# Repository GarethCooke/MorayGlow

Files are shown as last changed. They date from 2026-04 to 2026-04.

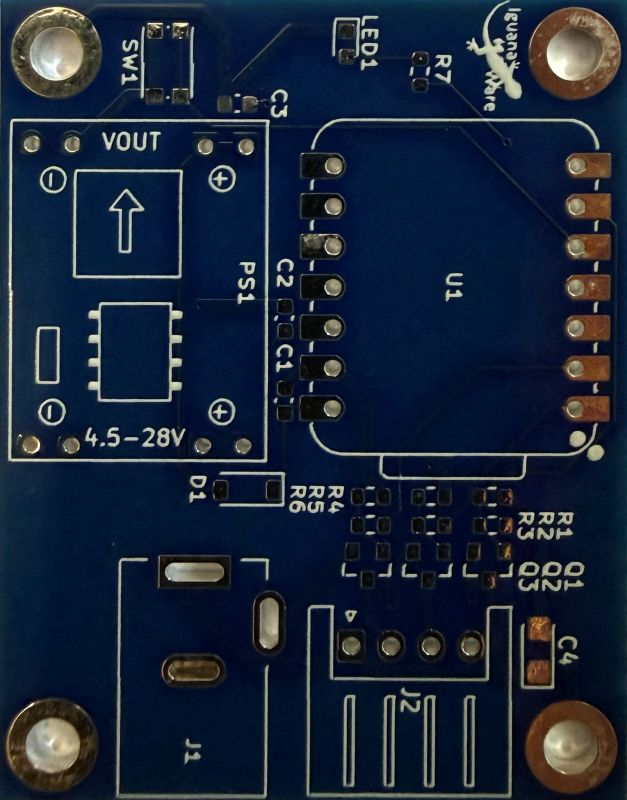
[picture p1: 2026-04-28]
docs/pcb-front.jpg

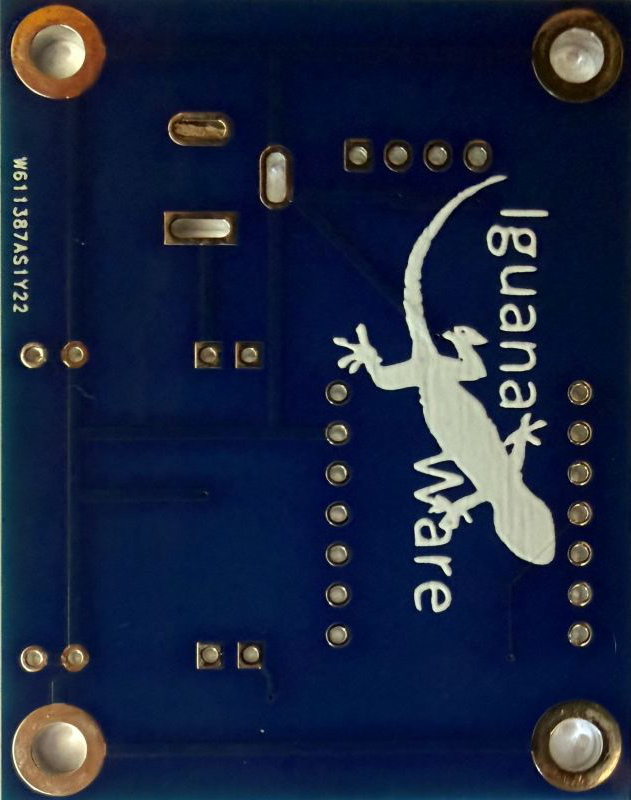
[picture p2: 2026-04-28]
docs/pcb-back.jpg

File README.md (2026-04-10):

# MorayGlow

IoT LED strip controller — ESP32 firmware + web UI with Home Assistant integration.

## Project Summary

MorayGlow controls an RGB LED strip via an **ESP32**. The device hosts a web UI and exposes a REST + WebSocket API. A browser-based client lets you toggle the strip on/off and pick a colour. The device also integrates with **Home Assistant** via MQTT auto-discovery, so it appears automatically as a light entity.

## Project Structure

```text
MorayGlow/
├── MorayServer/               # ESP32 firmware (C++, PlatformIO)
│   ├── platformio.ini
│   ├── src/main.cpp            # WiFi, LittleFS, REST API, WebSocket
│   ├── include/
│   │   ├── config.h            # WiFi credentials, MQTT config — edit before flashing
│   │   ├── state.h             # Pure logic: stateToJson, rgbToHex, parseMqttCommand
│   │   └── mqtt.h              # MQTT client + Home Assistant discovery
│   └── test/
│       └── test_state.cpp      # Unity tests (run on host, not device)
└── MorayClient/               # Web UI (plain HTML/CSS/JS — no framework)
    ├── index.html
    ├── css/style.css
    ├── js/
    │   ├── moray.js           # UMD utility module (buildWsUrl, isValidHexColor)
    │   └── app.js              # Main UI logic
    ├── test/
    │   └── moray.test.js      # Jest tests for moray.js
    └── test-server/            # Node.js mock server for UI development
        ├── server.js
        ├── logic.js            # Pure functions (testable without starting server)
        ├── db.json             # Persisted state between restarts
        └── test/
            └── server.test.js  # Jest tests for logic.js
```

## API

| Method | Endpoint | Body | Description |
| --- | --- | --- | --- |
| GET | `/api/state` | — | Returns `{"on": bool, "color": "#rrggbb"}` |
| POST | `/api/power` | `{"on": bool}` | Turn strip on or off |
| POST | `/api/color` | `{"color": "#rrggbb"}`  | Set strip colour |
| WS | `/ws` | — | Server pushes state on every change |

## Design Decisions

| Decision | Choice | Reason |
| --- | --- | --- |
| MCU | ESP32 Dev Board | Dual-core, Wi-Fi + Bluetooth built in |
| Build system | PlatformIO | Dependency management, board config, native test env |
| Web server | `esphome/ESPAsyncWebServer-esphome` | Supports ESP32; async |
| Filesystem | LittleFS | Serves client files from device flash |
| JSON | ArduinoJson v7 (`JsonDocument`) | No capacity arg needed; widely supported |
| MQTT | `knolleary/PubSubClient` + `setBufferSize(512)` | Lightweight, well-maintained |
| HA integration | MQTT auto-discovery | Device appears automatically in Home Assistant |
| Client | Plain HTML/CSS/JS (no framework) | Keeps LittleFS footprint small |
| Client module  | UMD pattern (`moray.js`) | Works as browser global and Node.js/Jest module |
| Testability | Pure functions in `state.h` / `logic.js` | Compiled and tested on host without hardware |
| C++ tests | Unity (via PlatformIO native env) | Bundled with PlatformIO; runs on host |
| JS tests | Jest | Standard, zero-config for CommonJS modules |

## Before Flashing

Edit `MorayServer/include/config.h` and set your WiFi SSID/password and MQTT broker IP before building and flashing.

## Running Tests

### MorayServer — C++ firmware (Unity via PlatformIO)

Requires `gcc`/`g++` on your PATH (install MinGW-w64 if not present).

```powershell
cd MorayServer
pio test -e native
```

### MorayClient — browser JS logic (Jest)

```powershell
cd MorayClient
npm install   # first time only
npm test
```

### Test server — Node.js logic (Jest)

```powershell
cd MorayClient\test-server
npm install   # first time only
npm test
```

---

## Starting the Test Server

The test server lets you develop and test the web UI without the physical device.

```powershell
cd MorayClient\test-server
npm install   # first time only
npm start
```

Then open [http://localhost:3000](http://localhost:3000) in a browser.

State is persisted to `MorayClient\test-server\db.json` between restarts.

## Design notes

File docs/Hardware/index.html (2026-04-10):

# MorayGlow — XIAO ESP32-S3 RGB LED Strip Controller

12 V 5050 RGB LED strip controller · Available as SMD or through-hole build

Seeed XIAO ESP32-S3 LEDC PWM 1 kHz 8-bit 12 V input · MP1584 buck SMD: IRLML6344TR SOT-23 TH: IRL540N TO-220 PlatformIO · ESP-IDF

## Schematic

Note: This schematic shows the circuit topology, which is identical for both SMD and through-hole builds. Only the package outlines differ — see the BOM and Assembly Notes sections below for component substitutions.

## Power Domains

+12V

J1 barrel jack → C3 (100nF) → MP1584 buck input · J2 pin-1 (strip common anode)
Main supply rail. Strip current limited by LED density; buck draws <200 mA additional.

+5V

MP1584 OUT → D1 (1N5819 Schottky, ~0.3V drop) → XIAO VBUS · C1 (100nF) · C2 (10µF)
Protected against USB/12V back-feed. XIAO draws <500 mA typical.

+3.3V

XIAO internal LDO → GPIO logic
LEDC outputs are 3.3 V — sufficient to drive both IRLML6344TR (Vgs(th)≈1.0V) and IRL540N (Vgs(th)≤2.0V).

GND

Common ground — J1 · MP1584 · XIAO GND pins · Q1–Q3 SOURCE · all pull-downs · LED1 · SW1 · C1–C3

## Pin Mapping

GPIO | XIAO Pin | Mode | LEDC | Function | Connected to
GPIO1 | D0 | PWM out | CH0 · 1kHz · 8-bit | Red channel | R1 (100Ω) → Q1 GATE
GPIO2 | D1 | PWM out | CH1 · 1kHz · 8-bit | Green channel | R2 (100Ω) → Q2 GATE
GPIO3 | D2 | PWM out | CH2 · 1kHz · 8-bit | Blue channel | R3 (100Ω) → Q3 GATE
GPIO4 | D3 | Digital out | — | Status LED | R7 (330Ω) → LED1 anode
GPIO5 | D4 | INPUT_PULLUP | — | Reset button | SW1 (active-LOW, hold 5s)

### Board Overview

XIAO ESP32-S3 front indication diagram

Seeed Studio XIAO ESP32-S3 — front view

### Full Pinout

XIAO ESP32-S3 pinout diagram

Source: Seeed Studio Wiki (https://wiki.seeedstudio.com/xiao_esp32s3_getting_started/)

## MOSFET Switch Topology

#### Circuit — identical for Q1 / Q2 / Q3

  GPIO ──[100Ω]──┬── GATE
                 │
               [10kΩ]
                 │          G
                GND         │
                         [MOSFET]
                            │ D ──── J2 (LED strip colour –)
                            │ S ──── GND

### Design rationale

Gate resistor (100Ω) | Limits inrush, damps ringing on fast PWM edges
Pull-down (10kΩ) | Holds gate LOW during boot / GPIO hi-Z — prevents strip flickering at reset
Common-anode strip | +12V to strip anode; MOSFETs sink each colour cathode
Logic compatibility | Both SMD and TH MOSFETs fully enhance at 3.3V — no level shifter needed

#### SMD — IRLML6344TR

Package | SOT-23
Vgs(th) | 0.5–1.5V (typ 1.0V)
Rds(on) | 22 mΩ @ Vgs = 4.5V
Id(max) | 5 A
Pinout | G · S · D (SOT-23 1·2·3)
Best for | PCB / compact design

#### Through-Hole — IRL540N

Package | TO-220
Vgs(th) | 1.0–2.0V (fully on at 3.3V)
Rds(on) | 77 mΩ @ Vgs = 5V · ≈120 mΩ @ 3.3V
Id(max) | 36 A
Pinout | G · D · S (flat face, left→right)
Best for | Breadboard / perfboard / stripboard

## Bill of Materials

SMD Build Through-Hole Build

Ref | Qty | Value | Description | Package | Part number
U1 | 1 | XIAO ESP32-S3 | Seeed XIAO ESP32-S3 Plus, castellated SMD | Module (castellated) | Seeed 113991116
Q1 | 1 | IRLML6344TR | N-Ch MOSFET, Vgs(th)≈1.0V, Id=5A — Red channel | SOT-23 | IRLML6344TRPBFCT-ND
Q2 | 1 | IRLML6344TR | N-Ch MOSFET, Vgs(th)≈1.0V, Id=5A — Green channel | SOT-23 | IRLML6344TRPBFCT-ND
Q3 | 1 | IRLML6344TR | N-Ch MOSFET, Vgs(th)≈1.0V, Id=5A — Blue channel | SOT-23 | IRLML6344TRPBFCT-ND
D1 | 1 | 1N5819HW-7-F | Schottky 40V 1A, USB/12V back-feed protection | SOD-123 | 1N5819HW-FDICT-ND
R1 R2 R3 | 3 | 100Ω | Gate resistors, 1/10W | 0603 | LCSC C22775
R4 R5 R6 | 3 | 10kΩ | Gate pull-downs, 1/10W | 0603 | LCSC C25804
R7 | 1 | 330Ω | Status LED current limiter, 1/10W | 0603 | LCSC C23138
C1 C3 | 2 | 100nF | Decoupling ceramic, 16–25V | 0603 | LCSC C14663
C2 | 1 | 10µF | Bulk cap, X5R 10V | 0805 | LCSC C15850
LED1 | 1 | LED Blue | Status indicator | 0805 | LCSC C72038
SW1 | 1 | SW_Push 6mm | Tactile pushbutton, SMD 4-pin | 6mm SMD | LCSC C318884
PS1 | 1 | MP1584 5V | Buck module 7–28V in / 5V 3A out | 2×2 header | Generic module
J1 | 1 | Barrel Jack | 12V DC input, 5.5/2.1mm SMD horizontal | SMD horizontal | LCSC C381116
J2 | 1 | Screw Term 4P | RGB strip connector, 3.5mm pitch SMD | 3.5mm SMD | LCSC C395916

Ref | Qty | Value | Description | Package | Part number | Notes
U1 | 1 | XIAO ESP32-S3 | Same XIAO module — mount in 2×7 female machine-pin sockets | 2×7 socket 2.54mm | Seeed 113991116 + sockets | XIAO has no TH pins — use castellated pad or pre-headered version
Q1 | 1 | IRL540N | N-Ch Logic Level MOSFET, Vgs(th)≤2.0V, Id=36A — Red | TO-220 | Digikey IRL540NPBF-ND | Pin order flat face L→R: G · D · S
Q2 | 1 | IRL540N | N-Ch Logic Level MOSFET, Vgs(th)≤2.0V, Id=36A — Green | TO-220 | Digikey IRL540NPBF-ND | No heatsink needed ≤3A/ch
Q3 | 1 | IRL540N | N-Ch Logic Level MOSFET, Vgs(th)≤2.0V, Id=36A — Blue | TO-220 | Digikey IRL540NPBF-ND | Rds(on) ≈ 100–150mΩ at 3.3V gate
D1 | 1 | 1N5819 | Schottky 40V 1A, USB/12V back-feed protection | DO-41 axial | LCSC C727110 | Cathode band (ring) toward XIAO VBUS
R1 R2 R3 | 3 | 100Ω | Gate resistors, 1/4W axial | DIN0207 10mm | LCSC C57430 | Carbon or metal film
R4 R5 R6 | 3 | 10kΩ | Gate pull-downs, 1/4W axial | DIN0207 10mm | LCSC C57690 | Carbon or metal film
R7 | 1 | 330Ω | Status LED current limiter, 1/4W axial | DIN0207 10mm | LCSC C57502 | Carbon or metal film
C1 C3 | 2 | 100nF | Decoupling ceramic disc, 50V — non-polarised | Disc 5mm pitch | LCSC C49678 | Orientation does not matter
C2 | 1 | 10µF 25V | Bulk cap, aluminium electrolytic radial | Radial 5mm pitch | LCSC C36369 | Long lead = positive (VBUS)
LED1 | 1 | LED Blue 5mm | Status indicator, 5mm through-hole | 5mm THT | LCSC C2296 | Long lead = anode; flat on lens = cathode
SW1 | 1 | SW_Push 6mm | Tactile pushbutton, 6×6mm through-hole | 6mm THT 4-pin | LCSC C318885 | Any orientation (leg pairs shorted internally)
PS1 | 1 | MP1584 5V | Same buck module — solder 2×2 headers, plug into board | 2×2 header | Generic module | Solder header pins to module first
J1 | 1 | Barrel Jack | 12V DC input, 5.5/2.1mm through-hole horizontal | THT horizontal | LCSC C136706 | Centre pin = +12V; sleeve = GND
J2 | 1 | Screw Term 4P | RGB strip connector, 3.5mm pitch through-hole | 3.5mm THT | LCSC C474870 | 5.08mm pitch also works: LCSC C8465

## Assembly Notes

● SMD-specific

1

IRLML6344TR SOT-23 pinout: looking at the component face with the marking text readable — pin 1 (Gate) is bottom-left, pin 2 (Source) is bottom-right, pin 3 (Drain) is at top. Use a fine-tip iron at 320°C.

2

1N5819HW SOD-123 polarity: the line on the body marks the cathode. On the PCB, the cathode side connects toward XIAO VBUS.

3

C2 0805 X5R: non-polarised ceramic — orientation does not matter. Solder last if hand-soldering to avoid disturbing adjacent small components.

● Through-hole-specific

1

IRL540N TO-220 pinout (flat face toward you, left→right): Gate · Drain · Source. Verify before soldering — incorrect orientation will short 12V to GND.

2

C2 electrolytic polarity: long lead = positive (+VBUS). Reversed polarity will destroy the cap. Mark the board clearly.

3

D1 (1N5819 DO-41) polarity: silver band = cathode. Cathode faces toward XIAO VBUS pin; anode faces MP1584 +5V output.

4

LED1 5mm polarity: long lead = anode. Current ≈ 4mA through R7 (330Ω from 3.3V) — sufficient for clear indicator visibility.

5

XIAO ESP32-S3: the module has no through-hole legs. Use 2×7 female machine-pin sockets soldered to the board so the module presses in. This also allows the module to be swapped without desoldering.

● Both builds

!

Test with low-voltage first: before connecting 12V, power the XIAO via USB and verify GPIO PWM signals at the gate resistor inputs with a multimeter. GATE voltage should cycle with PWM duty.

!

Power-up sequence: the 10kΩ gate pull-downs ensure all channels start OFF. The MP1584 module may take ~5ms to reach 5V; D1 prevents XIAO back-powering via USB when 12V is also connected.

## Firmware

### Build & Flash (PlatformIO)

# Build for XIAO ESP32-S3
pio run -e xiao_esp32s3

# Flash firmware
pio run -e xiao_esp32s3 -t upload

# Open serial monitor (115200 baud)
pio device monitor

⚠ XIAO GPIO restrictions
GPIO 19/20 = USB D+/D– — do not use for I/O.
GPIO 43/44 = TX/RX — keep free for Serial.

### Colour Cycle (3 s per step, auto-advance)

Red

Green

Blue

Yellow

Cyan

Magenta

White

Amber

### Reset Button Behaviour

Press < 5 s | No action
Holding… | Status LED blinks increasingly fast
Hold ≥ 5 s | 5× flash, then ESP.restart()
Debounce | 50 ms

MorayGlow — XIAO ESP32-S3 RGB LED Strip Controller · docs/Hardware/index.html

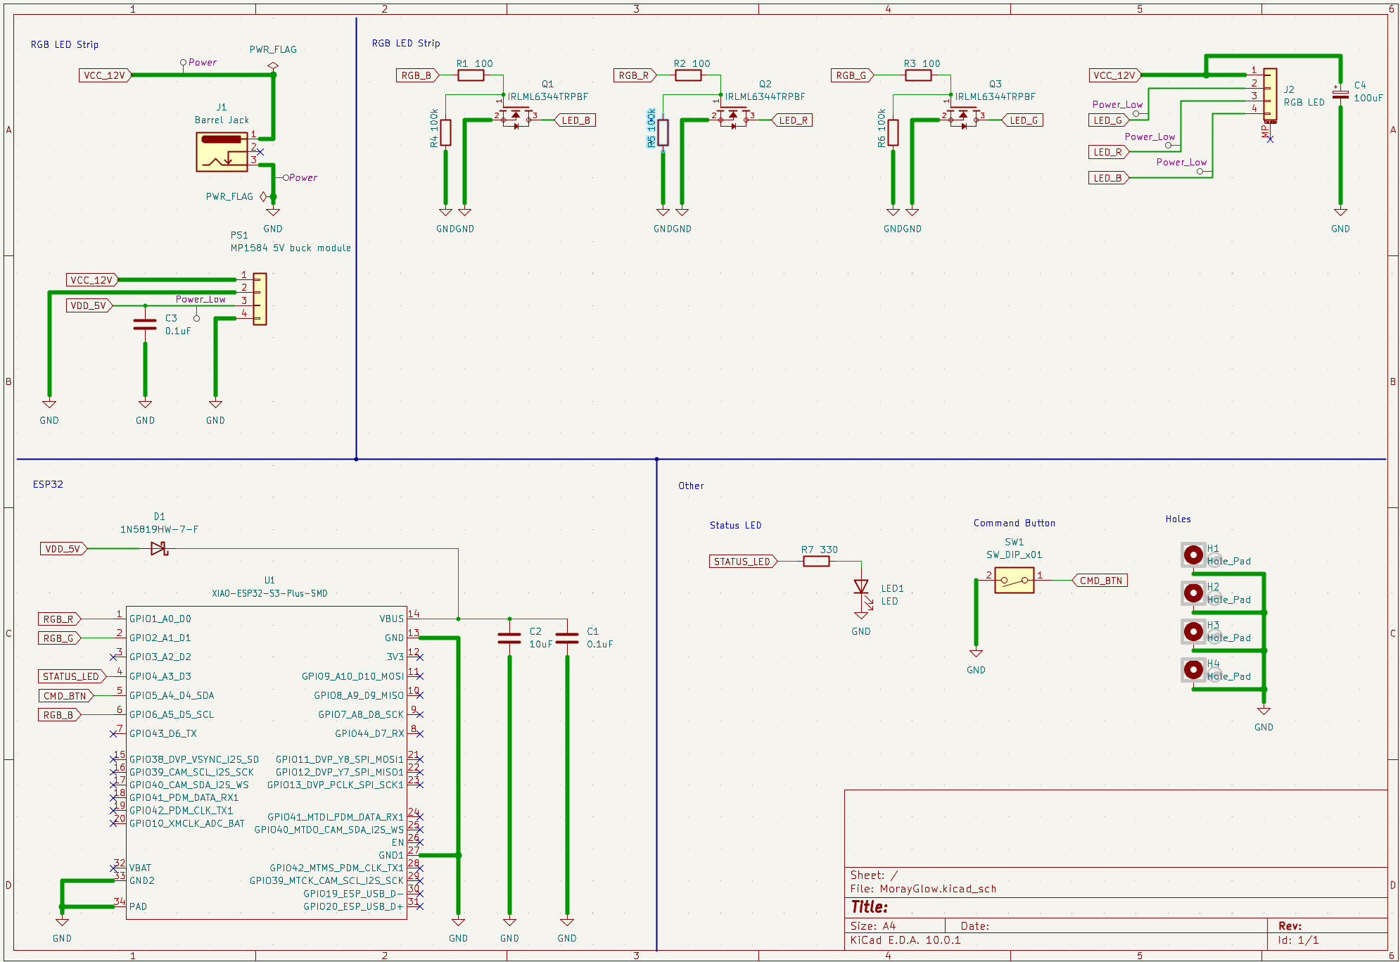
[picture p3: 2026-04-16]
docs/Hardware/schematic-kicad.png

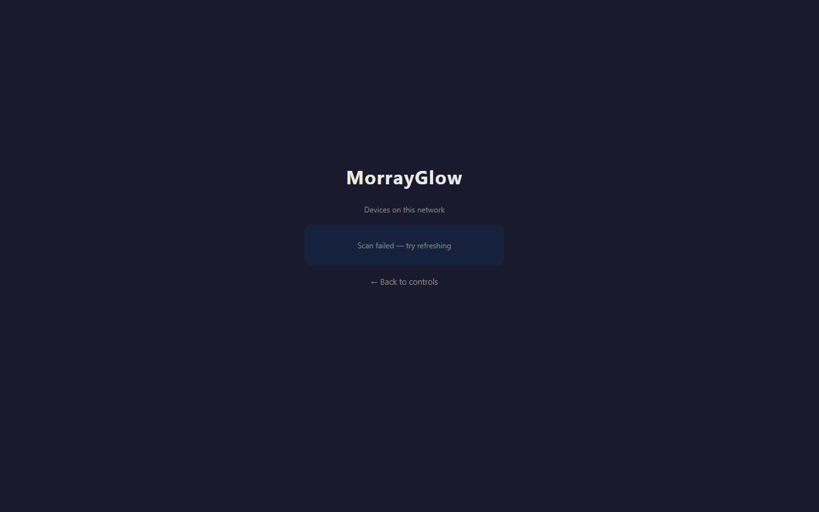
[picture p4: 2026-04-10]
docs/screenshots/ui-devices.png

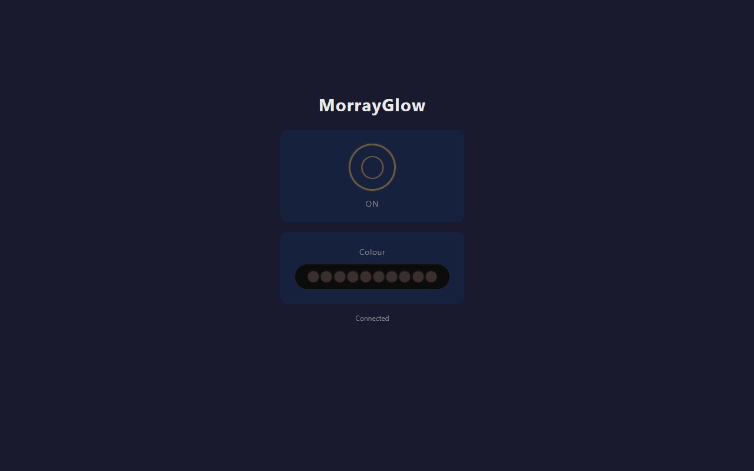
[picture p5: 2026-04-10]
docs/screenshots/ui-main.png

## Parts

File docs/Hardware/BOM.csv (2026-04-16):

MorayGlow — XIAO ESP32-S3 RGB LED Strip Controller
Bill of Materials — SMD and Through-Hole options
Generated: 2026-02-28
Circuit topology is identical for both builds; only packages and footprints differ.
================================================================================
=== SMD BUILD ===
Reference,Qty,Value,Description,Footprint,Part Number / Source
U1,1,XIAO ESP32-S3,Seeed XIAO ESP32-S3 Plus SMD module (castellated edges),Module:XIAO-ESP32-S3,Seeed 113991116
Q1,1,IRLML6344TR,N-Ch SOT-23 MOSFET Vgs(th)≈1.0V Id=5A Red channel,Package_TO_SOT_SMD:SOT-23,Digikey IRLML6344TRPBFCT-ND
Q2,1,IRLML6344TR,N-Ch SOT-23 MOSFET Vgs(th)≈1.0V Id=5A Green channel,Package_TO_SOT_SMD:SOT-23,Digikey IRLML6344TRPBFCT-ND
Q3,1,IRLML6344TR,N-Ch SOT-23 MOSFET Vgs(th)≈1.0V Id=5A Blue channel,Package_TO_SOT_SMD:SOT-23,Digikey IRLML6344TRPBFCT-ND
D1,1,1N5819HW-7-F,Schottky 40V 1A SOD-123 USB/12V back-feed protection,Diode_SMD:D_SOD-123,Digikey 1N5819HW-FDICT-ND
R1,1,100Ω,Gate resistor Q1 Red 1/10W 0603,Resistor_SMD:R_0603_1608Metric,LCSC C22775
R2,1,100Ω,Gate resistor Q2 Green 1/10W 0603,Resistor_SMD:R_0603_1608Metric,LCSC C22775
R3,1,100Ω,Gate resistor Q3 Blue 1/10W 0603,Resistor_SMD:R_0603_1608Metric,LCSC C22775
R4,1,100kΩ,Gate pull-down Q1 1/10W 0603,Resistor_SMD:R_0603_1608Metric,LCSC C25803
R5,1,100kΩ,Gate pull-down Q2 1/10W 0603,Resistor_SMD:R_0603_1608Metric,LCSC C25803
R6,1,100kΩ,Gate pull-down Q3 1/10W 0603,Resistor_SMD:R_0603_1608Metric,LCSC C25803
R7,1,330Ω,Status LED current limiter 1/10W 0603,Resistor_SMD:R_0603_1608Metric,LCSC C23138
C1,1,100nF,VBUS decoupling ceramic 16V 0603,Capacitor_SMD:C_0603_1608Metric,LCSC C14663
C2,1,10µF,VBUS bulk cap X5R 10V 0805,Capacitor_SMD:C_0805_2012Metric,LCSC C15850
C3,1,100nF,VDD_5V output decoupling ceramic 25V 0603 (on PS1 VOUT),Capacitor_SMD:C_0603_1608Metric,LCSC C14663
C4,1,100µF,VCC_12V bulk cap — absorbs PWM switching transients near J2 Kemet A SMD,Capacitor_SMD:CP_EIA-3216-18_Kemet-A,LCSC C16780
LED1,1,LED Blue,Status indicator 0805,LED_SMD:LED_0805_2012Metric,LCSC C72038
SW1,1,SW_Push,Tactile pushbutton 6mm SMD 4-pin,Button_Switch_SMD:SW_SPST_PTS645,LCSC C318884
PS1,1,MP1584 Buck 5V,Buck module 7-28V in / 5V 3A out — connect via 2.54mm headers,Connector_PinHeader_2.54mm:PinHeader_2x02_P2.54mm_Vertical,Generic module
J1,1,Barrel Jack 5.5/2.1,12V DC input SMD horizontal,Connector_BarrelJack:BarrelJack_Horizontal,LCSC C381116
J2,1,Screw Terminal 4P 3.5mm,RGB strip connector SMD,Connector_Phoenix_MC:PhoenixContact_MC_1,5_4-G-3.5_1x04,LCSC C395916
=== THROUGH-HOLE BUILD ===
Reference,Qty,Value,Description,Footprint,Part Number / Source,Notes
U1,1,XIAO ESP32-S3,Same XIAO module soldered to 2×7 2.54mm female pin sockets,2×7 2.54mm socket headers,Seeed 113991116 + sockets,XIAO has 0.7mm hole pitch — use castellated SMD or buy with pre-soldered headers
Q1,1,IRL540N,N-Ch TO-220 Logic Level MOSFET Vgs(th)≤2.0V Id=36A Red channel,Package_TO_SOT_THT:TO-220-3_Vertical,Digikey IRL540NPBF-ND,3.3V gate drive gives ~100-150mΩ Rds(on) — fully adequate for strip current
Q2,1,IRL540N,N-Ch TO-220 Logic Level MOSFET Vgs(th)≤2.0V Id=36A Green channel,Package_TO_SOT_THT:TO-220-3_Vertical,Digikey IRL540NPBF-ND,Pin order: G=1 D=2 S=3 (flat face toward you left to right)
Q3,1,IRL540N,N-Ch TO-220 Logic Level MOSFET Vgs(th)≤2.0V Id=36A Blue channel,Package_TO_SOT_THT:TO-220-3_Vertical,Digikey IRL540NPBF-ND,No heatsink needed at ≤3A per channel
D1,1,1N5819,Schottky 40V 1A DO-41 axial USB/12V back-feed protection,Diode_THT:D_DO-41_SOD81_P10.16mm_Horizontal,LCSC C727110,Cathode band toward XIAO VBUS pin
R1,1,100Ω,Gate resistor Q1 Red 1/4W axial,Resistor_THT:R_Axial_DIN0207_L6.3mm_D2.5mm_P10.16mm_Horizontal,LCSC C57430,Standard carbon film 1/4W
R2,1,100Ω,Gate resistor Q2 Green 1/4W axial,Resistor_THT:R_Axial_DIN0207_L6.3mm_D2.5mm_P10.16mm_Horizontal,LCSC C57430,Standard carbon film 1/4W
R3,1,100Ω,Gate resistor Q3 Blue 1/4W axial,Resistor_THT:R_Axial_DIN0207_L6.3mm_D2.5mm_P10.16mm_Horizontal,LCSC C57430,Standard carbon film 1/4W
R4,1,100kΩ,Gate pull-down Q1 1/4W axial,Resistor_THT:R_Axial_DIN0207_L6.3mm_D2.5mm_P10.16mm_Horizontal,LCSC C57692,Standard carbon film 1/4W
R5,1,100kΩ,Gate pull-down Q2 1/4W axial,Resistor_THT:R_Axial_DIN0207_L6.3mm_D2.5mm_P10.16mm_Horizontal,LCSC C57692,Standard carbon film 1/4W
R6,1,100kΩ,Gate pull-down Q3 1/4W axial,Resistor_THT:R_Axial_DIN0207_L6.3mm_D2.5mm_P10.16mm_Horizontal,LCSC C57692,Standard carbon film 1/4W
R7,1,330Ω,Status LED current limiter 1/4W axial,Resistor_THT:R_Axial_DIN0207_L6.3mm_D2.5mm_P10.16mm_Horizontal,LCSC C57502,Standard carbon film 1/4W
C1,1,100nF,VBUS decoupling ceramic disc 50V 5mm pitch,Capacitor_THT:C_Disc_D5.0mm_W2.5mm_P5.00mm,LCSC C49678,Non-polarised — orientation does not matter
C2,1,10µF 25V,VBUS bulk cap aluminium electrolytic radial 5mm pitch,Capacitor_THT:CP_Radial_D5.0mm_P2.50mm,LCSC C36369,Polarised — long lead = positive (VBUS)
C3,1,100nF,VDD_5V output decoupling ceramic disc 50V 5mm pitch (on PS1 VOUT),Capacitor_THT:C_Disc_D5.0mm_W2.5mm_P5.00mm,LCSC C49678,Non-polarised — orientation does not matter
C4,1,100µF 16V,VCC_12V bulk cap — absorbs PWM switching transients near J2 radial electrolytic,Capacitor_THT:CP_Radial_D6.3mm_P2.50mm,LCSC C36370,Polarised — long lead = positive (+12V)
LED1,1,LED Blue 5mm,Status indicator 5mm through-hole LED,LED_THT:LED_D5.0mm,LCSC C2296,Long lead = anode (+) — cathode has flat on lens rim
SW1,1,SW_Push 6mm,Tactile pushbutton 6×6mm through-hole,Button_Switch_THT:SW_Tactile_Straight_KSA0Axx1LFTR,LCSC C318885,All four legs are equivalent pairs — orientation does not matter
PS1,1,MP1584 Buck 5V,Same buck module — connect via 2×2 2.54mm pin headers soldered in,Connector_PinHeader_2.54mm:PinHeader_2x02_P2.54mm_Vertical,Generic module,Solder 4 header pins to module pads first
J1,1,Barrel Jack 5.5/2.1,12V DC input through-hole horizontal,Connector_BarrelJack:BarrelJack_Horizontal,LCSC C136706 / CUI PJ-002AH,Centre pin = +12V; sleeve = GND
J2,1,Screw Terminal 4P 3.5mm,RGB strip connector through-hole 3.5mm pitch,Connector_Phoenix_MC:PhoenixContact_MC_1,5_4-G-3.5_1x04_THT,LCSC C474870,Or use 5.08mm pitch (more common in TH): LCSC C395916-TH

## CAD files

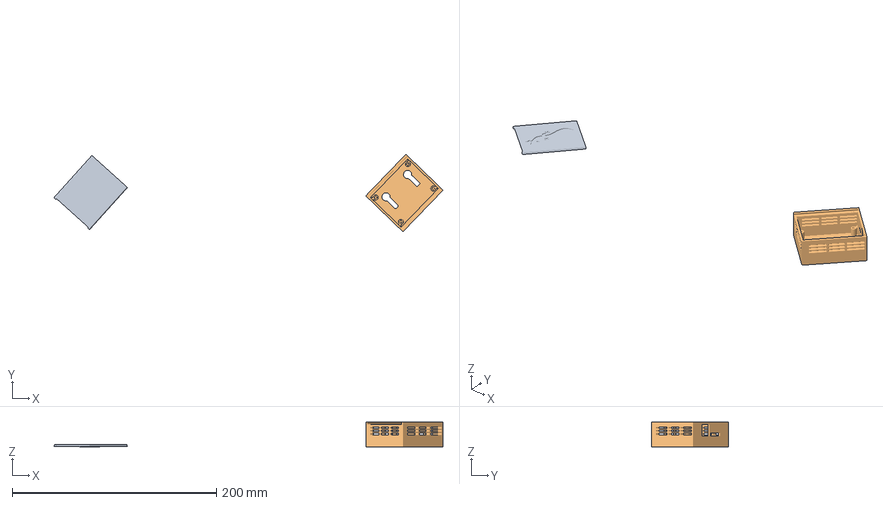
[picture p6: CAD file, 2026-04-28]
Enclosure/MorrayGlow encosure.3mf
380.5 x 75.6 x 24.0 mm
MorrayGlow encosure x 2

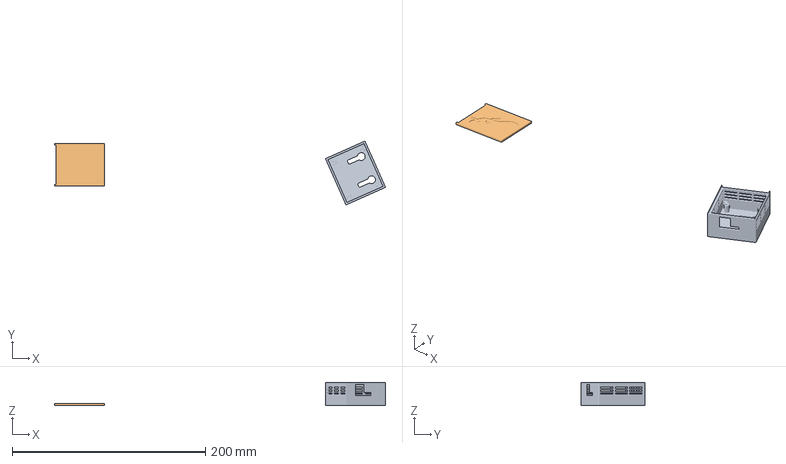
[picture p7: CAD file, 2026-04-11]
Enclosure/MorayGlow enclosure.3mf
342.1 x 65.9 x 24.0 mm
Box - Base
Assembly

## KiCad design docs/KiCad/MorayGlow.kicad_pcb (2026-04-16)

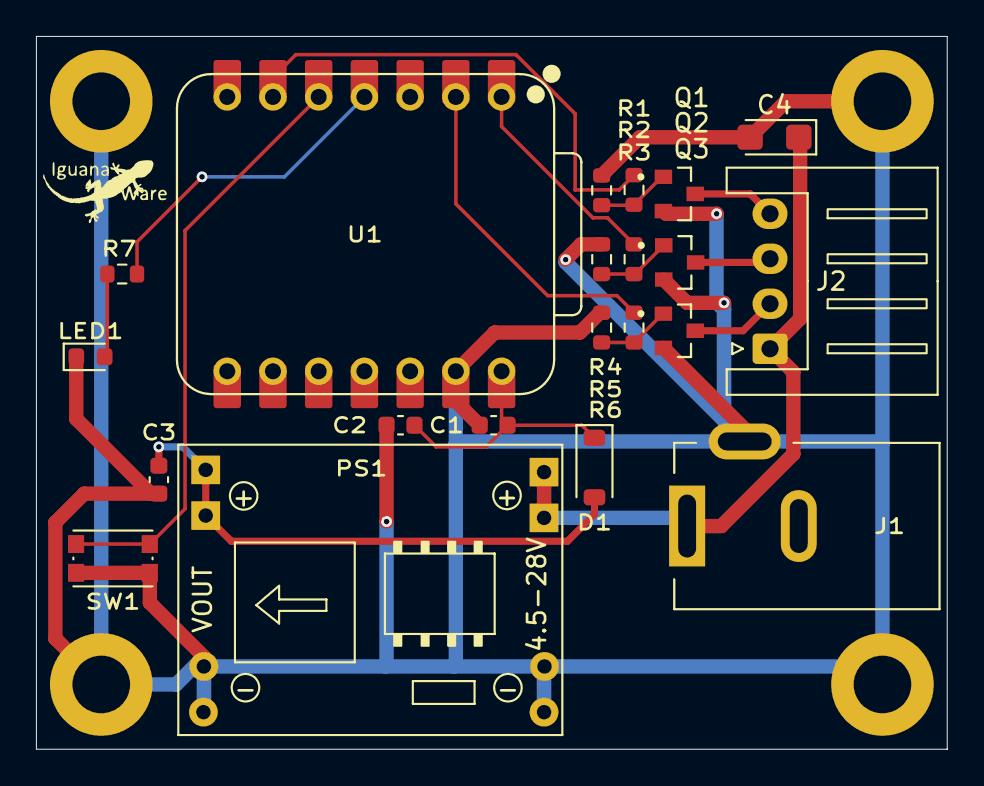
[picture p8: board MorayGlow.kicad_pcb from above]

Board: 2 copper layers, 50.6 x 39.6 mm, 25 parts (0 on the bottom side), 16 nets.

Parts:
C1, C3: 0.1uF; C_0603_1608Metric
C2: 10uF; C_0603_1608Metric
C4: 100uF; CP_EIA-3216-18_Kemet-A
D1: 1N5819HW-7-F; D_SOD-123
H1, H2, H3, H4: Hole_Pad; MountingHole_3.2mm_M3_ISO7380_Pad
J1: Barrel Jack; BarrelJack_Kycon_KLDX-0202-xC_Horizontal
J2: RGB LED; JST_XH_S4B-XH-A_1x04_P2.50mm_Horizontal
LED1: LED; LED_0603_1608Metric
PS1: MP1584 5V buck module; SRT_MPT1584EN_Module
Q1, Q2, Q3: IRLML6344TRPBF; TRANS_IRLML6344TRPBF
R1, R2, R3: 100; R_0603_1608Metric
R4, R5, R6: 100k; R_0603_1608Metric
R7: 330; R_0603_1608Metric
SW1: SW_DIP_x01; SW_Push_1P1T_NO_CK_KMR2
U1: XIAO-ESP32-S3-Plus-SMD; XIAO-ESP32-S3-DIP

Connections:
CMD_BTN: SW1.1, U1.5 (GPIO5_A4_D4_SDA)
GND: C1.2, C2.2, C3.1, C4.2, H1.1 (1_1), H2.1 (1_1), H3.1 (1_1), H4.1 (1_1), J1.3, LED1.1 (K), PS1.2, PS1.4, Q1.2, Q2.2, Q3.2, R4.2, R5.2, R6.2, SW1.2, U1.13 (GND)
LED_B: J2.4, Q1.3
LED_G: J2.2, Q3.3
LED_R: J2.3, Q2.3
unnamed: C1.1, C2.1, D1.1 (K), U1.14 (VBUS)
unnamed: LED1.2 (A), R7.1
unnamed: Q1.1, R1.1, R4.1
unnamed: Q2.1, R2.1, R5.1
unnamed: Q3.1, R3.1, R6.1
RGB_B: R1.2, U1.6 (GPIO6_A5_D5_SCL)
RGB_G: R3.2, U1.2 (GPIO2_A1_D1)
RGB_R: R2.2, U1.1 (GPIO1_A0_D0)
STATUS_LED: R7.2, U1.4 (GPIO4_A3_D3)
VCC_12V: C4.1, J1.1, J2.1, PS1.1
VDD_5V: C3.2, D1.2 (A), PS1.3

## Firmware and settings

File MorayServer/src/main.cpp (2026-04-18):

// MorayGlow — XIAO ESP32-S3 RGB LED Strip Controller
// Hardware: Seeed XIAO ESP32-S3, IRLML6344TR MOSFETs, MP1584 buck, 12V 5050 RGB strip
// See docs/Hardware/ for schematic, netlist, and BOM.
//
// PIN MAPPING
//   PIN_RED    GPIO1  D0  LEDC CH0  PWM 1kHz 8-bit
//   PIN_GREEN  GPIO2  D1  LEDC CH1  PWM 1kHz 8-bit
//   PIN_BLUE   GPIO6  D5  LEDC CH2  PWM 1kHz 8-bit  (GPIO3 is a strapping pin — avoid)
//   PIN_STATUS GPIO4  D3  Output    Status LED (via 330Ω to GND)
//   PIN_BUTTON GPIO5  D4  Input     INPUT_PULLUP · hold 5s = factory reset

#include <Arduino.h>
#include <ButtonStatus.h>
#include <TwoStateValue.h>

#include <EspDevice.h>
#include <EspProvision.h>

#include "config.h"
#include "mqtt.h"
#include "state.h"
#include "webserver.h"

#define PIN_RED    1
#define PIN_GREEN  2
#define PIN_BLUE   6
#define PIN_STATUS 4
#define PIN_BUTTON 5

#define LEDC_CH_RED     0
#define LEDC_CH_GREEN   1
#define LEDC_CH_BLUE    2
#define LEDC_FREQ_HZ    1000
#define LEDC_RESOLUTION 8

#define HOLD_DURATION_MS          5000
#define FLASH_COUNT               5
#define FLASH_ON_MS               150
#define FLASH_OFF_MS              150
#define COLOUR_CHANGE_INTERVAL_MS 3000

struct Colour { uint8_t r, g, b; };

const Colour colourSequence[] = {
    {255, 0, 0}, {0, 255, 0}, {0, 0, 255}, {255, 255, 0},
    {0, 255, 255}, {255, 0, 255}, {255, 255, 255}, {255, 128, 0},
};
const uint8_t NUM_COLOURS   = sizeof(colourSequence) / sizeof(colourSequence[0]);
uint8_t       currentColour = 0;

// ── LED state — referenced as extern by webserver.cpp and mqtt.cpp ───────────
bool   ledOn     = false;
String ledColor  = "#ffffff";
bool   cycleMode = true;

ButtonStatus* pBtn          = nullptr;
uint32_t      lastColourChange = 0;

// ── Hardware helpers ──────────────────────────────────────────────────────────

static void blinkStatus(int count, uint32_t onMs, uint32_t offMs) {
    for (int i = 0; i < count; i++) {
        digitalWrite(PIN_STATUS, HIGH); delay(onMs);
        digitalWrite(PIN_STATUS, LOW);  delay(offMs);
    }
}

static void setupLedChannel(uint8_t channel, uint8_t pin) {
    ledcSetup(channel, LEDC_FREQ_HZ, LEDC_RESOLUTION);
    ledcAttachPin(pin, channel);
}

void setColour(uint8_t r, uint8_t g, uint8_t b) {
    ledcWrite(LEDC_CH_RED, r);
    ledcWrite(LEDC_CH_GREEN, g);
    ledcWrite(LEDC_CH_BLUE, b);
}

void applyLedState() {
    if (!ledOn) { setColour(0, 0, 0); return; }
    long c = strtol(ledColor.c_str() + 1, nullptr, 16);
    setColour((c >> 16) & 0xFF, (c >> 8) & 0xFF, c & 0xFF);
}

// ── Arduino lifecycle ─────────────────────────────────────────────────────────

void setup() {
    Serial.begin(115200);
    pinMode(PIN_STATUS, OUTPUT);

    setupLedChannel(LEDC_CH_RED,   PIN_RED);
    setupLedChannel(LEDC_CH_GREEN, PIN_GREEN);
    setupLedChannel(LEDC_CH_BLUE,  PIN_BLUE);

    pBtn = new ButtonStatus(
        make_shared_ptr_lite<TwoStateValue>(new DigitalPinValue(PIN_BUTTON, false)));
    pinMode(PIN_BUTTON, INPUT_PULLUP);

    Provision.onStation([](AsyncWebServer& srv) {
        webserverSetup(srv);
        String mqttUser = Provision.getMqttUser();
        String mqttPass = Provision.getMqttPass();
        Mqtt.setup(EspDevice::id().c_str(), mqttUser.c_str(), mqttPass.c_str());
    });

    EspProvisionConfig cfg;
    cfg.apPassword       = "morayglow";
    cfg.nvsNamespace     = "morayglow";
    cfg.otaPassword      = OTA_PASSWORD;
    cfg.friendlyHostname = "morayglow";
    cfg.serviceType      = "morayglow";
    Provision.begin("morayglow", "MorayGlow", cfg);

    blinkStatus(2, 200, 200);
    applyLedState();
    digitalWrite(PIN_STATUS, HIGH);
    lastColourChange = millis();
}

void loop() {
    Provision.loop();

    if (!Provision.isApMode()) {
        webserverLoop();
        Mqtt.loop();
    }

    uint32_t now = millis();

    // ── Hold-to-reset: blink faster as hold approaches 5 s ──────────────────
    static uint32_t btnDownStart = 0;
    if (pBtn->isOn()) {
        if (btnDownStart == 0) btnDownStart = now;
        uint32_t held      = now - btnDownStart;
        uint32_t blinkRate = map(constrain(held, 0, HOLD_DURATION_MS),
                                 0, HOLD_DURATION_MS, 800, 80);
        digitalWrite(PIN_STATUS, ((now / blinkRate) % 2) ? HIGH : LOW);
        if (held >= HOLD_DURATION_MS) {
            setColour(0, 0, 0);
            blinkStatus(FLASH_COUNT, FLASH_ON_MS, FLASH_OFF_MS);
            Provision.factoryReset();
        }
    } else {
        btnDownStart = 0;
        digitalWrite(PIN_STATUS, HIGH);
    }

    // ── Auto colour cycle every 3 s ──────────────────────────────────────────
    if (cycleMode && !pBtn->isOn() && (now - lastColourChange >= COLOUR_CHANGE_INTERVAL_MS)) {
        currentColour        = (currentColour + 1) % NUM_COLOURS;
        const Colour& c      = colourSequence[currentColour];
        ledOn                = true;
        ledColor             = rgbToHex(c.r, c.g, c.b);
        applyLedState();
        if (!Provision.isApMode()) {
            broadcastState();
            Mqtt.publishState();
        }
        lastColourChange = now;
    }
}

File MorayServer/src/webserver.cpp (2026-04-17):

#include "webserver.h"

#include <ArduinoJson.h>
#include <AsyncWebSocket.h>
#include <ESPAsyncWebServer.h>
#include <LittleFS.h>
#include <Preferences.h>
#include <ESPmDNS.h>
#include <WiFi.h>
#include <map>
#include <string>

#include "config.h"
#include "mqtt.h"
#include "state.h"

#include <EspDevice.h>
#include <EspProvision.h>

// State globals defined in main.cpp
extern bool   ledOn;
extern String ledColor;
extern bool   cycleMode;
extern void   applyLedState();

static AsyncWebSocket _ws("/ws");

// ── Async WiFi scan (station mode — for in-app network reconfiguration) ───────

static int  _scanCount = WIFI_SCAN_FAILED;
static bool _scanReady = false;

static void pollScan() {
    int result = WiFi.scanComplete();
    if (result == WIFI_SCAN_RUNNING) return;
    if (result >= 0) {
        _scanCount = result;
        _scanReady = true;
    } else {
        _scanReady = false;
        WiFi.scanNetworks(/*async=*/true);
    }
}

void broadcastState() {
    _ws.textAll(stateToJson(ledOn, ledColor, cycleMode));
}

// ── Body handler helpers ──────────────────────────────────────────────────────

static bool parseJsonBody(uint8_t* data, size_t len, size_t index, size_t total,
                          JsonDocument& doc, AsyncWebServerRequest* req) {
    if (index + len < total) return false;
    if (deserializeJson(doc, (char*)data, len) != DeserializationError::Ok) {
        req->send(400, "application/json", "{\"error\":\"invalid JSON\"}");
        return false;
    }
    return true;
}

static void broadcastAndRespond(AsyncWebServerRequest* req) {
    broadcastState();
    Mqtt.publishState();
    req->send(200, "application/json", stateToJson(ledOn, ledColor, cycleMode));
}

static void applyAndRespond(AsyncWebServerRequest* req) {
    applyLedState();
    broadcastAndRespond(req);
}

// ── Body handlers ─────────────────────────────────────────────────────────────

static void onBody_power(AsyncWebServerRequest* req, uint8_t* data, size_t len,
                         size_t index, size_t total) {
    JsonDocument doc;
    if (!parseJsonBody(data, len, index, total, doc, req)) return;
    if (!doc["on"].is<bool>()) {
        req->send(400, "application/json", "{\"error\":\"on required\"}");
        return;
    }
    ledOn = doc["on"].as<bool>();
    applyAndRespond(req);
}

static void onBody_color(AsyncWebServerRequest* req, uint8_t* data, size_t len,
                         size_t index, size_t total) {
    JsonDocument doc;
    if (!parseJsonBody(data, len, index, total, doc, req)) return;
    const char* color = doc["color"] | "";
    if (strlen(color) != 7 || color[0] != '#') {
        req->send(400, "application/json", "{\"error\":\"invalid color\"}");
        return;
    }
    ledColor  = color;
    cycleMode = false;
    applyAndRespond(req);
}

static void onBody_mode(AsyncWebServerRequest* req, uint8_t* data, size_t len,
                        size_t index, size_t total) {
    JsonDocument doc;
    if (!parseJsonBody(data, len, index, total, doc, req)) return;
    if (!doc["cycle"].is<bool>()) {
        req->send(400, "application/json", "{\"error\":\"cycle required\"}");
        return;
    }
    cycleMode = doc["cycle"].as<bool>();
    broadcastAndRespond(req);
}

static void onBody_networkset(AsyncWebServerRequest* req, uint8_t* data, size_t len,
                              size_t index, size_t total) {
    JsonDocument doc;
    if (!parseJsonBody(data, len, index, total, doc, req)) return;
    const char* ssid = doc["ssid"] | "";
    if (strlen(ssid) == 0) {
        req->send(400, "application/json", "{\"error\":\"ssid required\"}");
        return;
    }
    req->send(200, "application/json", "{\"ok\":true}");
    Provision.saveCredentialsAndRestart(ssid, doc["password"] | "");
}

// ── Setup / loop ──────────────────────────────────────────────────────────────

void webserverSetup(AsyncWebServer& server) {
    _ws.onEvent([](AsyncWebSocket*, AsyncWebSocketClient* client, AwsEventType type,
                   void*, uint8_t*, size_t) {
        if (type == WS_EVT_CONNECT) client->text(stateToJson(ledOn, ledColor, cycleMode));
    });
    server.addHandler(&_ws);

    server.on("/api/state", HTTP_GET, [](AsyncWebServerRequest* req) {
        req->send(200, "application/json", stateToJson(ledOn, ledColor, cycleMode));
    });

    server.on("/api/deviceinfo", HTTP_GET, [](AsyncWebServerRequest* req) {
        JsonDocument doc;
        doc["id"]   = EspDevice::id();
        doc["name"] = EspDevice::name();
        doc["url"]  = EspDevice::url();
        String out;
        serializeJson(doc, out);
        req->send(200, "application/json", out);
    });

    server.on("/api/devices", HTTP_GET, [](AsyncWebServerRequest* req) {
        // mDNS query for peer MorayGlow devices — blocks ~2 s
        JsonDocument doc;
        JsonArray arr = doc["devices"].to<JsonArray>();
        JsonObject self = arr.add<JsonObject>();
        self["id"]  = EspDevice::id();
        self["ip"]  = WiFi.localIP().toString();
        self["url"] = EspDevice::url();
        int found = MDNS.queryService("morayglow", "tcp");
        for (int i = 0; i < found; i++) {
            String peerId = MDNS.hostname(i);
            if (peerId.endsWith(".local")) peerId = peerId.substring(0, peerId.length() - 6);
            if (peerId == EspDevice::id()) continue;
            JsonObject peer = arr.add<JsonObject>();
            peer["id"]  = peerId;
            peer["ip"]  = MDNS.IP(i).toString();
            peer["url"] = "http://" + peerId + ".local";
        }
        String out;
        serializeJson(doc, out);
        req->send(200, "application/json", out);
    });

    server.on("/api/networkdata", HTTP_GET, [](AsyncWebServerRequest* req) {
        if (!_scanReady) {
            req->send(200, "application/json", "{\"scanning\":true,\"networks\":[]}");
            return;
        }
        struct NetInfo { int rssi; bool secure; };
        std::map<std::string, NetInfo> best;
        for (int i = 0; i < _scanCount; i++) {
            std::string ssid   = WiFi.SSID(i).c_str();
            int         rssi   = WiFi.RSSI(i);
            bool        secure = (WiFi.encryptionType(i) != WIFI_AUTH_OPEN);
            auto it = best.find(ssid);
            if (it == best.end() || rssi > it->second.rssi)
                best[ssid] = {rssi, secure};
        }
        JsonDocument doc;
        doc["scanning"] = false;
        JsonArray arr   = doc["networks"].to<JsonArray>();
        for (auto& entry : best) {
            JsonObject net = arr.add<JsonObject>();
            net["ssid"]    = entry.first.c_str();
            net["rssi"]    = entry.second.rssi;
            net["secure"]  = entry.second.secure;
        }
        String out;
        serializeJson(doc, out);
        req->send(200, "application/json", out);
        _scanReady = false;
        WiFi.scanDelete();
        WiFi.scanNetworks(/*async=*/true);
    });
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

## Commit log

2026-04-10 Initial commit — graduated from Arduino mono-repo
    [BOM.csv, MorayGlow.kicad_pcb, MorayGlow.kicad_sch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]
2026-04-10 Rename Morray → Moray throughout (directories, files, content)
    Corrects the double-r typo in MorrayClient/ → MorayClient/,
    MorrayServer/ → MorayServer/, morray.js → moray.js, and all
    internal references across source, config, and docs.
    [main.cpp, mqtt.cpp]
2026-04-11 Add hardware BOM and KiCad schematic to project docs
    - New #bom section with tabbed SMD / through-hole parts tables (sourced from docs/Hardware/BOM.csv)
    - KiCad schematic screenshot added to #schematic section alongside existing SVG diagram
    - BOM nav entry added to sidebar
2026-04-11 Add image zoom (lightbox) to schematic and screenshots
    - .zoomable CSS class (cursor: zoom-in) opts any standalone image into the lightbox
    - KiCad schematic image marked zoomable
    - Lightbox JS selector extended to cover .screenshot-card img and .zoomable
2026-04-11 Add enclosure model, update KiCad PCB and project files
    - Enclosure/MorrayGlow encosure.3mf — 3D printable enclosure model
    - docs/KiCad/MorayGlow.kicad_pcb — PCB layout updates
    - docs/KiCad/MorayGlow.kicad_prl — project local settings update
    - docs/KiCad/fp-info-cache — footprint cache refresh
    - Remove stale KiCad schematic lock file
    [MorayGlow.kicad_pcb, MorrayGlow encosure.3mf]
2026-04-11 Rename enclosure file to fix typos
    MorrayGlow encosure.3mf → MorayGlow enclosure.3mf
    [MorayGlow enclosure.3mf]
2026-04-11 Update enclosure 3MF model
    [MorayGlow enclosure.3mf]
2026-04-12 Add morayglow.local alias, fix lib path, add VS Code deploy tasks
    - Register generic mDNS alias (morayglow.local) via mdns_delegate_hostname_add
    so the device is reachable without knowing the MAC-based hostname
    - Fix lib_extra_dirs path (../../../Arduino/Common) so IguanaLib headers resolve
    - Add .vscode/tasks.json with USB and OTA upload tasks for firmware and filesystem
    [main.cpp]
2026-04-16 Apply schematic review changes: GPIO fix, component updates, new KiCad files
    - Fix critical bug: PIN_BLUE moved from GPIO3 to GPIO6 (D5) — GPIO3 is an
    ESP32-S3 strapping pin that could cause boot issues
    - R4/R5/R6 gate pull-downs changed 10kΩ → 100kΩ (saves ~1mA, adequate for
    IRLML6344 gate leakage)
    - C3 moved from VCC_12V input to VDD_5V output of MP1584 (correct placement)
    - C4 100µF added on VCC_12V at J2 to absorb PWM switching transients
    - Update KiCad schematic, PCB, and project files with all reviewed changes
    - Update docs/Hardware/BOM.csv, circuit_reference.txt, and docs/index.html
    - Remove stale fabrication-toolkit production outputs (can be regenerated)
    - Add KiCad .lck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
    [BOM.csv, MorayGlow.kicad_pcb, MorayGlow.kicad_sch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]
2026-04-17 Migrate to IguanaPlatform and IguanaCommon; add WiFi settings UI
    - Replace Device/WiFiConfig/IguanaOTA with EspProvision/EspDevice from IguanaPlatform
    - Remove device.h/device.cpp (replaced by EspDevice)
    - MqttLight now subclasses EspMqttBase
    - Add /api/deviceinfo endpoint; add WiFi settings link to index.html
    - Mock server now serves directly from MorayServer/data/ (single source of truth)
    - Update lib_extra_dirs to IguanaCommon (moved from Arduino/Common)
    - Ignore c_cpp_properties.json and compile_commands.json
    [main.cpp, mqtt.cpp]
2026-04-17 Add friendlyHostname/serviceType to EspProvision config; fix platformio.ini lib paths
    [main.cpp]
2026-04-22 Add light/dark theme toggle to web UI; convert setup.html to shared CSS
    Unified style.css with light/dark mode (class-based toggle, localStorage
    persistence, FOUC-prevention). setup.html converted from inline styles
    to css/style.css. Icon-only theme toggle button on all pages.
2026-04-28 updated pcb imags - new pcb
    [MorrayGlow encosure.3mf]
